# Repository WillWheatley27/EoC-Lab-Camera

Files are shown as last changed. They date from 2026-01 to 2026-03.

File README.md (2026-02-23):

| Supported Targets | ESP32 | ESP32-P4 | ESP32-S3 |
| --- | ----- | --- | --- |

# ESP32-S3 SD + Mic + OV2640 Recorder

__WARNING:__ This project writes audio/video files to the SD card. Back up your data before testing.

Records:
- **Audio**: WAV via I2S mic (ICS-43434), `mic_0001.wav`, `mic_0002.wav`, ...
- **Video**: MJPEG via OV2640, `VID0001.MJP`, `VID0002.MJP`, ...

Core features:
- SDMMC FAT mount/unmount
- USB MSC to expose the SD card when idle
- SSD1306 I2C OLED status
- Button + buzzer UI
- BLE scan trigger (advertisements) with timestamped filenames

Supports SD (SDSC, SDHC, SDXC) cards and eMMC.

## Quick wiring map (ESP32-S3)

- **SD card:** GPIO4/5/6/7/15/16 (SDMMC)
- **Mic (I2S):** GPIO19/20/21
- **OLED (I2C):** GPIO41/42 (addr `0x3C`)
- **Camera (OV2640 SCCB):**
  - SCCB SDA: GPIO47
  - SCCB SCL: GPIO48
  - XCLK: GPIO3 (10 MHz)
  - D0..D7: GPIO8, 9, 10, 11, 12, 13, 14, 17
  - PCLK: GPIO18
  - VSYNC: GPIO21
  - HREF: GPIO46
  - PWDN/RESET: tied in hardware (PWDN → GND, RESET → 3.3V)

## Hardware

This project targets ESP32-S3 and uses an SD card breakout or slot, an I2S mic, an SSD1306 OLED, and an OV2640 camera.

Although it is possible to connect an SD card breakout adapter, keep in mind that connections using breakout cables are often unreliable and have poor signal integrity. You may need to use lower clock frequency when working with SD card breakout adapters.

This project doesn't utilize card detect (CD) and write protect (WP) signals from SD card slot.

### Pin assignments for ESP32

On ESP32, SDMMC peripheral is connected to specific GPIO pins using the IO MUX. GPIO pins cannot be customized. Please see the table below for the pin connections.

When using an ESP-WROVER-KIT board, this example runs without any extra modifications required. Only an SD card needs to be inserted into the slot.

ESP32 pin     | SD card pin | Notes
--------------|-------------|------------
GPIO14 (MTMS) | CLK         | 10k pullup in SD mode
GPIO15 (MTDO) | CMD         | 10k pullup in SD mode
GPIO2         | D0          | 10k pullup in SD mode, pull low to go into download mode (see Note about GPIO2 below!)
GPIO4         | D1          | not used in 1-line SD mode; 10k pullup in 4-line SD mode
GPIO12 (MTDI) | D2          | not used in 1-line SD mode; 10k pullup in 4-line SD mode (see Note about GPIO12 below!)
GPIO13 (MTCK) | D3          | not used in 1-line SD mode, but card's D3 pin must have a 10k pullup

### Pin assignments for ESP32-S3 (current project)

On ESP32-S3, SDMMC peripheral is connected to GPIO pins using GPIO matrix. This allows arbitrary GPIOs to be used to connect an SD card. In this example, GPIOs can be configured in two ways:

1. Using menuconfig: Run `idf.py menuconfig` in the project directory and open "SD/MMC Example Configuration" menu.
2. In the source code: See the initialization of `sdmmc_slot_config_t slot_config` structure in the example code.

The table below lists the default pin assignments.

When using an ESP32-S3-USB-OTG board, this example runs without any extra modifications required. Only an SD card needs to be inserted into the slot.

ESP32-S3 pin  | SD card pin | Notes
--------------|-------------|------------
GPIO4         | CLK         | 10k pullup
GPIO5         | CMD         | 10k pullup
GPIO6         | D0          | 10k pullup
GPIO7         | D1          | 10k pullup
GPIO15        | D2          | 10k pullup
GPIO16        | D3          | 10k pullup (required even in 1-line mode)

### I2S mic (ICS-43434)

ESP32-S3 pin  | Mic pin
--------------|---------
GPIO19        | BCLK/SCK
GPIO20        | WS/LRCL
GPIO21        | DOUT/SD
3.3V          | VCC
GND           | GND

SEL/LR on the mic should be tied to GND (left channel), which matches the code.

### OLED (SSD1306, I2C)

ESP32-S3 pin  | OLED pin
--------------|---------
GPIO41        | SDA
GPIO42        | SCL
3.3V          | VCC
GND           | GND

I2C address is `0x3C`.
Note: On ESP32-S3-DevKitC-1, GPIO41/42 are JTAG pins. Disable JTAG in `idf.py menuconfig` so they can be used for I2C.

### Camera (OV2640, Waveshare) — read this first

This project uses OV2640 over SCCB (I2C). The camera is sensitive to pin choice and initial frames are often corrupted.

**Working pin map (ESP32-S3):**

ESP32-S3 pin | OV2640 pin | Notes
-------------|------------|------
GPIO47       | SCCB SDA   | Camera I2C data
GPIO48       | SCCB SCL   | Camera I2C clock
GPIO3        | XCLK       | External clock (10 MHz)
GPIO8        | D0         | Data bit 0
GPIO9        | D1         | Data bit 1
GPIO10       | D2         | Data bit 2
GPIO11       | D3         | Data bit 3
GPIO12       | D4         | Data bit 4
GPIO13       | D5         | Data bit 5
GPIO14       | D6         | Data bit 6
GPIO17       | D7         | Data bit 7
GPIO18       | PCLK       | Pixel clock
GPIO21       | VSYNC      | Frame sync
GPIO46       | HREF       | Line sync

PWDN and RESET are tied in hardware (PWDN -> GND, RESET -> 3.3V). In software, they are disabled (set to `-1`).

**What was broken and how it was fixed:**

- SCCB was originally on GPIO36/37, which are used internally by Octal flash/PSRAM on ESP32-S3-WROOM-2, so SCCB traffic failed.
  Fix: move SCCB to GPIO47/48 and set `sccb_i2c_port = I2C_NUM_0`.
- OLED and camera shared an I2C bus, and we mixed old I2C driver with a driver_ng wrapper, causing a runtime abort.
  Fix: split buses (OLED on I2C1 GPIO41/42, camera SCCB on I2C0 GPIO47/48) and remove SCCB mutex usage.
- Early frames were corrupted (NO-SOI/NO-EOI) and were written to file.
  Fix: discard the first 10 frames after init and only write frames with valid SOI/EOI markers.
- FATFS without LFN rejected long filenames.
  Fix: use 8.3 filename `VID0001.MJP`.
- OLED writes could overlap between tasks and hang I2C.
  Fix: serialize OLED I2C writes with a mutex and remove SD warning OLED spam.

**Playback note:** `VIDxxxx.MJP` is a raw MJPEG stream (not a container). VLC can play it; for QuickTime, convert to AVI/MP4.

### BLE trigger and timestamped filenames

The device scans BLE advertisements and uses a UUID-encoded timestamp to name files:

- **Video:** `MMDDHHMM.MJP`
- **Audio:** `MMDDHHMM.WAV`

If no valid BLE timestamp is seen, it falls back to the index names:

- `VID0001.MJP`
- `mic_0001.wav`

**UUID format (128-bit):** `00000000-0000-0000-TT00-YYMMDDHHMMSS`

- Prefix is fixed: all zeroes (`00 00 00 00 00 00 00 00`)
- `TT` = `01` short press, `02` long press
- `YYMMDDHHMMSS` are BCD digits (base-10 nibbles)
- Filenames use `MMDDHHMM` to stay 8.3-safe

### Button + buzzer

ESP32-S3 pin  | Device
--------------|---------
GPIO1         | Button (pull-up input)
GPIO2         | Passive buzzer (PWM output)

### Pin assignments for ESP32-P4

On ESP32-P4, Slot 1 of the SDMMC peripheral is connected to GPIO pins using GPIO matrix. This allows arbitrary GPIOs to be used to connect an SD card. In this example, GPIOs can be configured in two ways:

1. Using menuconfig: Run `idf.py menuconfig` in the project directory and open `SD/MMC Example Configuration` menu.
2. In the source code: See the initialization of `sdmmc_slot_config_t slot_config` structure in the example code.

The table below lists the default pin assignments.

ESP32-P4 pin  | SD card pin | Notes
--------------|-------------|------------
GPIO43        | CLK         | 10k pullup
GPIO44        | CMD         | 10k pullup
GPIO39        | D0          | 10k pullup
GPIO40        | D1          | not used in 1-line SD mode; 10k pullup in 4-line mode
GPIO41        | D2          | not used in 1-line SD mode; 10k pullup in 4-line mode
GPIO42        | D3          | not used in 1-line SD mode, but card's D3 pin must have a 10k pullup

Default dedicated pins on ESP32-P4 are able to connect to an ultra high-speed SD card (UHS-I) which requires 1.8V switching (instead of the regular 3.3V). This means the user has to provide an external LDO power supply to use them, or to enable and configure an internal LDO via `idf.py menuconfig` -> `SD/MMC Example Configuration` -> `SD power supply comes from internal LDO IO`.

When using different GPIO pins this is not required and `SD power supply comes from internal LDO IO` setting can be disabled.

### 4-line and 1-line SD modes

By default, this example uses 4 line SD mode, utilizing 6 pins: CLK, CMD, D0 - D3. It is possible to use 1-line mode (CLK, CMD, D0) by changing "SD/MMC bus width" in the example configuration menu (see `CONFIG_EXAMPLE_SDMMC_BUS_WIDTH_1`).

Note that even if card's D3 line is not connected to the ESP chip, it still has to be pulled up, otherwise the card will go into SPI protocol mode.

### Note about GPIO2 (ESP32 only)

GPIO2 pin is used as a bootstrapping pin, and should be low to enter UART download mode. One way to do this is to connect GPIO0 and GPIO2 using a jumper, and then the auto-reset circuit on most development boards will pull GPIO2 low along with GPIO0, when entering download mode.

- Some boards have pulldown and/or LED on GPIO2. LED is usually ok, but pulldown will interfere with D0 signals and must be removed. Check the schematic of your development board for anything connected to GPIO2.

### Note about GPIO12 (ESP32 only)

GPIO12 is used as a bootstrapping pin to select output voltage of an internal regulator which powers the flash chip (VDD_SDIO). This pin has an internal pulldown so if left unconnected it will read low at reset (selecting default 3.3V operation). When adding a pullup to this pin for SD card operation, consider the following:

- For boards which don't use the internal regulator (VDD_SDIO) to power the flash, GPIO12 can be pulled high.
- For boards which use 1.8V flash chip, GPIO12 needs to be pulled high at reset. This is fully compatible with SD card operation.
- On boards which use the internal regulator and a 3.3V flash chip, GPIO12 must be low at reset. This is incompatible with SD card operation.
    * In most cases, external pullup can be omitted and an internal pullup can be enabled using a `gpio_pullup_en(GPIO_NUM_12);` call. Most SD cards work fine when an internal pullup on GPIO12 line is enabled. Note that if ESP32 experiences a power-on reset while the SD card is sending data, high level on GPIO12 can be latched into the bootstrapping register, and ESP32 will enter a boot loop until external reset with correct GPIO12 level is applied.
    * Another option is to burn the flash voltage selection efuses. This will permanently select 3.3V output voltage for the internal regulator, and GPIO12 will not be used as a bootstrapping pin. Then it is safe to connect a pullup resistor to GPIO12. This option is suggested for production use.

The following command can be used to program flash voltage selection efuses **to 3.3V**:

```sh
    espefuse.py set_flash_voltage 3.3V
```

This command will burn the `XPD_SDIO_TIEH`, `XPD_SDIO_FORCE`, and `XPD_SDIO_REG` efuses. With all three burned to value 1, the internal VDD_SDIO flash voltage regulator is permanently enabled at 3.3V. See the technical reference manual for more details.

`espefuse.py` has a `--do-not-confirm` option if running from an automated flashing script.

See [the document about pullup requirements](https://docs.espressif.com/projects/esp-idf/en/latest/api-reference/peripherals/sd_pullup_requirements.html) for more details about pullup support and compatibility of modules and development boards.

## How to use

### Build and flash

Build the project and flash it to the board, then run monitor tool to view serial output:

```
idf.py -p PORT flash monitor
```

(Replace PORT with serial port name.)

(To exit the serial monitor, type ``Ctrl-]``.)

### Recording flow

1. Long press starts recording. USB MSC is stopped and the SD card is mounted to the app.
2. Audio is written to `mic_0001.wav`, `mic_0002.wav`, etc.
3. Long press again stops recording, finalizes the WAV header, and returns the SD card to USB MSC.
4. A later long press repeats the cycle with a new filename.

Short press toggles pause/resume during recording. Each press produces a short beep.

### SD card mount warnings

If SD mounting fails or is not ready, the OLED shows a warning:

- `SD init failed`
- `SD mount failed`
- `SD not ready`

When these appear, re-seat the SD card and try again. Also wait for the
`Exposing SD card over USB` log before unplugging or copying files.

See the Getting Started Guide for full steps to configure and use ESP-IDF to build projects.

### USB mass storage

When idle, the SD card is exposed over USB MSC for file access from your computer.
During recording, USB MSC is stopped and the SD card is mounted to the application.
After recording finishes, USB MSC is restarted and the card is visible again on the host.

## Example output

Here is an example console output. In this case a 128MB SDSC card was connected, and `EXAMPLE_FORMAT_IF_MOUNT_FAILED` menuconfig option enabled. Card was unformatted, so the initial mount has failed. Card was then partitioned, formatted, and mounted again.

```
I (336) example: Initializing SD card
I (336) example: Using SDMMC peripheral
I (420) example: Mounting filesystem
I (538) mic: Waiting for long press
I (1840) button: Recording started
I (1841) mic: Recording started
I (9620) mic: Stop requested
I (9622) mic: Captured 7 sec to /sdcard/mic_0001.wav
I (9660) example: Card unmounted
```

## Troubleshooting

### Failure to download the example

```
Connecting........_____....._____....._____....._____....._____....._____....._____

A fatal error occurred: Failed to connect to Espressif device: Invalid head of packet (0x34)
```

Disconnect the SD card D0/MISO line from GPIO2 and try uploading again. Read "Note about GPIO2" above.

### Card fails to initialize with `sdmmc_init_sd_scr: send_scr (1) returned 0x107` error

Check connections between the card and the ESP32. For example, if you have disconnected GPIO2 to work around the flashing issue, connect it back and reset the ESP32 (using a button on the development board, or by pressing Ctrl-T Ctrl-R in IDF Monitor).

### Card fails to initialize with `sdmmc_check_scr: send_scr returned 0xffffffff` error

Connections between the card and the ESP32 are too long for the frequency used. Try using shorter connections, or try reducing the clock speed of SD interface.

### Failure to mount filesystem

```
example: Failed to mount filesystem. If you want the card to be formatted, set the EXAMPLE_FORMAT_IF_MOUNT_FAILED menuconfig option.
```
The example will be able to mount only cards formatted using FAT32 filesystem. If the card is formatted as exFAT or some other filesystem, you have an option to format it in the example code. Enable the `EXAMPLE_FORMAT_IF_MOUNT_FAILED` menuconfig option, then build and flash the example.

### Debug SD connections and pullup strength

> If the initialization of the SD card fails, initially follow the above options. If the issue persists, confirm the connection of pullups to the SD pins. To do this, enable the` Debug sd pin connections and pullup strength` option from menuconfig and rerun the code. This will provide the following result:

```
**** PIN recovery time ****

PIN 14 CLK  10044 cycles
PIN 15 CMD  10034 cycles
PIN  2  D0  10034 cycles
PIN  4  D1  10034 cycles
PIN 12  D2  10034 cycles
PIN 13  D3  10034 cycles

**** PIN recovery time with weak pullup ****

PIN 14 CLK  100 cycles
PIN 15 CMD  100 cycles
PIN  2  D0  100 cycles
PIN  4  D1  100 cycles
PIN 12  D2  100 cycles
PIN 13  D3  100 cycles

**** PIN voltage levels ****

PIN 14 CLK  0.6V
PIN 15 CMD  0.3V
PIN  2  D0  0.8V
PIN  4  D1  0.6V
PIN 12  D2  0.4V
PIN 13  D3  0.8V

**** PIN voltage levels with weak pullup ****

PIN 14 CLK  1.0V
PIN 15 CMD  1.1V
PIN  2  D0  1.0V
PIN  4  D1  1.0V
PIN 12  D2  1.0V
PIN 13  D3  1.2V

**** PIN cross-talk ****

              CLK   CMD    D0    D1    D2    D3
PIN 14 CLK     --   0.2V  0.1V  0.1V  0.1V  0.2V
PIN 15 CMD    0.1V   --   0.1V  0.1V  0.1V  0.1V
PIN  2  D0    0.1V  0.1V   --   0.2V  0.1V  0.1V
PIN  4  D1    0.1V  0.1V  0.3V   --   0.1V  0.1V
PIN 12  D2    0.1V  0.2V  0.2V  0.1V   --   0.1V
PIN 13  D3    0.1V  0.2V  0.1V  0.1V  0.1V   --

**** PIN cross-talk with weak pullup ****

              CLK   CMD    D0    D1    D2    D3
PIN 14 CLK     --   1.0V  1.0V  1.0V  1.0V  1.2V
PIN 15 CMD    0.9V   --   1.0V  1.0V  1.0V  1.2V
PIN  2  D0    0.9V  1.0V   --   1.0V  1.0V  1.2V
PIN  4  D1    0.9V  1.0V  1.2V   --   1.0V  1.2V
PIN 12  D2    0.9V  1.1V  1.2V  0.9V   --   1.2V
PIN 13  D3    0.9V  1.2V  1.1V  0.9V  0.9V   --
I (845) main_task: Returned from app_main()
```

In the absence of connected pullups and having the weak pullups enabled, you can assess the pullup connections by comparing PIN recovery time measured in CPU cycles. To check pullup connections, configure the pin as open drain, set it to low state, and count the cpu cycles consumed before returning to high state. If a pullup is connected, the pin will get back to high state after reasonably small cycle count, typically around 50-300 cycles, depending on pullup strength. If no pullup is connected, the PIN stays low and the measurement times out after 10000 cycles.

It will also provide the voltage levels at the corresponding SD pins. By default, this information is provided for ESP32 chip only, and for other chipsets, verify the availability of ADC pins for the respective GPIO using [this](https://docs.espressif.com/projects/esp-idf/en/latest/esp32/api-reference/peripherals/gpio.html#gpio-summary) and configure ADC mapped pins using menuconfig. Then test the voltage levels accordingly.

You can monitor the voltage levels of individual pins using `PIN voltage levels` and `PIN voltage levels with weak pullup`. However, if one pin being pulled low and experiencing interference with another pin, you can detect it through `PIN cross-talk` and `PIN cross-talk with weak pullup`. In the absence of pullups, voltage levels at each pin should range from 0 to 0.3V. With 10k pullups connected, the voltage will be between 3.1V to 3.3V, contingent on the connection between ADC pins and SD pins, and with weak pullups connected, it can fluctuate between 0.8V to 1.2V, depending on pullup strength.
>>>>>>> 207d2c1 (Initial commit)

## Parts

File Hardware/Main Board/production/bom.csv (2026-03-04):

Designator | Footprint | Quantity | Value | LCSC Part #
BOOT1, RESET1 | SW_SPST_EVQP7A | 2 | SW_Push
BT1 | JST_GH_SM02B-GHS-TB_1x02-1MP_P1.25mm_Horizontal | 1 | Battery_Cell
C1, C3, C8 | 0402 | 3 | 0.1uF
C10, C2, C7 | 0402 | 3 | 10uF
C11, C12, C13 | 0805 | 3 | 22uF
C4, C5, C6 | 0603 | 3 | 10uF
C9 | 0402 | 1 | 10pF
D1, D2, D3, D4 | 0603 | 4 | LED
D5 | D_SMA | 1 | SS14
F1 | 1206 | 1 | Fuse
J1 | microSD_HC_Molex_104031-0811 | 1 | Micro_SD_Card_Det1
J2 | PinHeader_2x09_P2.54mm_Vertical | 1 | Camera Module
J3 | JST_GH_SM09B-GHS-TB_1x09-1MP_P1.25mm_Horizontal | 1 | Conn_01x09_Socket
J4 | JST_GH_SM06B-GHS-TB_1x06-1MP_P1.25mm_Horizontal | 1 | MIC 1 Connector
J5 | JST_GH_SM06B-GHS-TB_1x06-1MP_P1.25mm_Horizontal | 1 | MIC 2 Connector
J6 | USB_C_Receptacle_HRO_TYPE-C-31-M-12 | 1 | USB_C_Receptacle_USB2.0_16P
J7 | PinHeader_1x04_P2.54mm_Vertical | 1 | OLED
L1 | L_Bourns-SRN4018 | 1 | 1uH
Q1 | SOT-23 | 1 | AO3401A
R1, R11, R12 | 0402 | 3 | 10k
R10, R23, R8, R9 | 0402 | 4 | 22
R13, R14, R20 | 0402 | 3 | 1k
R15 | 0402 | 1 | 0.4
R16 | 0402 | 1 | 560k
R17 | 0402 | 1 | 4.7k
R18, R24 | 0402 | 2 | 100k
R19 | 0402 | 1 | 1M
R2, R3, R4, R5, R6, R7 | 0402 | 6 | 47k
R21, R22 | 0402 | 2 | 5.1k
TP1, TP2, TP3 | PinHeader_1x01_P2.54mm_Vertical | 3 | TestPoint
TP4, TP5, TP6 | TestPoint_Pad_1.0x1.0mm | 3 | TestPoint
U1 | ESP32-S3-WROOM-2 | 1 | ESP32-S3-WROOM-2
U2 | Texas_S-PWSON-N10_ThermalVias | 1 | TPS63060
U3 | SOIC-8-1EP_3.9x4.9mm_P1.27mm_EP2.41x3.3mm_ThermalVias | 1 | TP4056-42-ESOP8
USER_INPUT1 | SW_SPST_PTS645 | 1 | SW_Push

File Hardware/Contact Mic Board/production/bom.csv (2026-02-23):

Designator | Footprint | Quantity | Value | LCSC Part #
C1, C16, C18, C19, C3, C5, C6 | 0402 | 7 | 0.1uF
C10, C13, C8, C9 | 0402 | 4 | 1uF
C11, C12 | 0402 | 2 | 470nF
C14, C15, C17, C2, C4, C7 | 0402 | 6 | 10uF
FB1 | 0603 | 1 | FerriteBead_Small
J1 | JST_GH_SM09B-GHS-TB_1x09-1MP_P1.25mm_Horizontal | 1 | Conn_01x09_Pin
R1, R2 | 0402 | 2 | 47k
R10, R9 | 0402 | 2 | 1M
R11, R12, R13, R14 | 0402 | 4 | 33
R3, R4 | 0402 | 2 | 10M
R5, R6 | 0805 | 2 | 100k
R7, R8 | 0402 | 2 | 10K
U1 | QFN-28-1EP_4x4mm_P0.45mm_EP2.6x2.6mm | 1 | ES8388
U2 | DFN-8-1EP_3x2mm_P0.5mm_EP1.75x1.45mm | 1 | MCP6002-xMC

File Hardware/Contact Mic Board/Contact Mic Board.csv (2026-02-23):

Reference | Qty | Value | DNP | Exclude from BOM | Exclude from Board | Footprint | Datasheet
C1,C3,C5,C6,C16,C18,C19 | 7 | 0.1uF |  |  |  | Capacitor_SMD:C_0402_1005Metric | ~
C2,C4,C7,C14,C15,C17 | 6 | 10uF |  |  |  | Capacitor_SMD:C_0402_1005Metric | ~
C8,C9,C10,C13 | 4 | 1uF |  |  |  | Capacitor_SMD:C_0402_1005Metric | ~
C11,C12 | 2 | 470nF |  |  |  | Capacitor_SMD:C_0402_1005Metric | ~
FB1 | 1 | FerriteBead_Small |  |  |  | Capacitor_SMD:C_0603_1608Metric | ~
J1 | 1 | Conn_01x09_Pin |  |  |  | Connector_JST:JST_GH_SM09B-GHS-TB_1x09-1MP_P1.25mm_Horizontal | ~
MIC1 | 1 | Contact Mic 1 |  | Excluded from BOM |  | Connector_PinHeader_2.54mm:PinHeader_1x02_P2.54mm_Vertical | ~
MIC2 | 1 | Contact Mic 2 |  | Excluded from BOM |  | Connector_PinHeader_2.54mm:PinHeader_1x02_P2.54mm_Vertical | ~
R1,R2 | 2 | 47k |  |  |  | Capacitor_SMD:C_0402_1005Metric | ~
R3,R4 | 2 | 10M |  |  |  | Capacitor_SMD:C_0402_1005Metric | ~
R5,R6 | 2 | 100k |  |  |  | Diode_SMD:D_0805_2012Metric_Pad1.15x1.40mm_HandSolder | ~
R7 | 1 | 10K |  |  |  | Capacitor_SMD:C_0402_1005Metric | ~
R8 | 1 | 10k |  |  |  | Capacitor_SMD:C_0402_1005Metric | ~
R9,R10 | 2 | 1M |  |  |  | Capacitor_SMD:C_0402_1005Metric | ~
R11,R12,R13,R14 | 4 | 33 |  |  |  | Capacitor_SMD:C_0402_1005Metric | ~
TP1,TP2,TP3,TP4 | 4 | TestPoint |  |  |  | TestPoint:TestPoint_Pad_1.0x1.0mm | ~
U1 | 1 | ES8388 |  |  |  | Package_DFN_QFN:QFN-28-1EP_4x4mm_P0.45mm_EP2.6x2.6mm | http://www.everest-semi.com/pdf/ES8388%20DS.pdf
U2 | 1 | MCP6002-xMC |  |  |  | Package_DFN_QFN:DFN-8-1EP_3x2mm_P0.5mm_EP1.75x1.45mm | http://ww1.microchip.com/downloads/en/DeviceDoc/21733j.pdf

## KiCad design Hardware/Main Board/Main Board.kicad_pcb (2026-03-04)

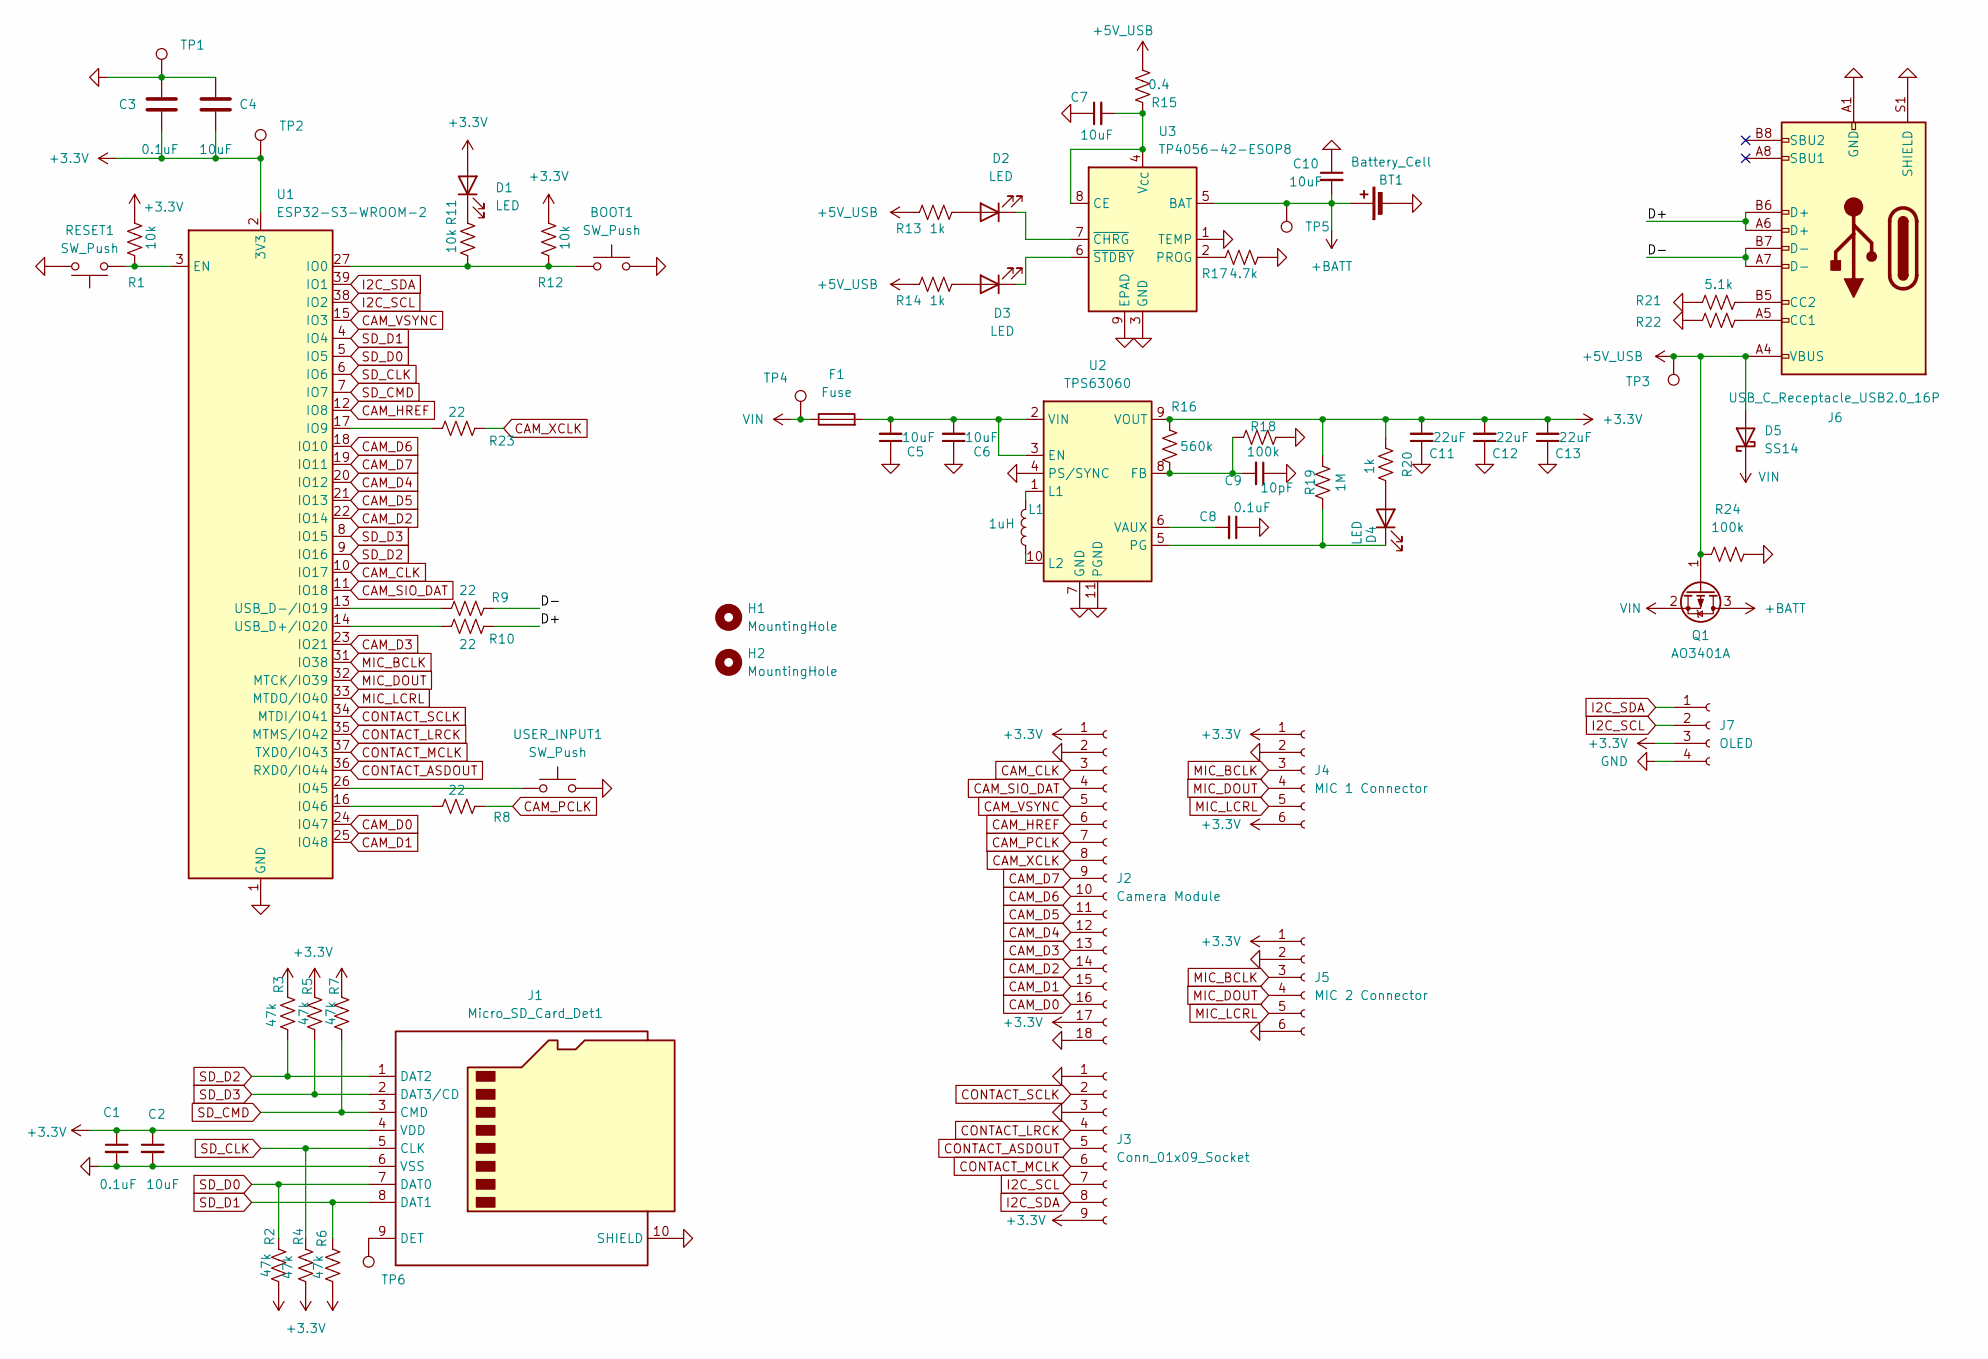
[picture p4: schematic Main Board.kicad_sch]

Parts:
BOOT1: SW_Push; SW_SPST_EVQP7A
BT1: Battery_Cell; JST_GH_SM02B-GHS-TB_1x02-1MP_P1.25mm_Horizontal
C1, C3, C8: 0.1uF; C_0402_1005Metric
C2, C7, C10: 10uF; C_0402_1005Metric
C4, C5, C6: 10uF; C_0603_1608Metric
C9: 10pF; C_0402_1005Metric
C11, C12, C13: 22uF; C_0805_2012Metric
D1, D2, D3, D4: LED; LED_0603_1608Metric
D5: SS14; D_SMA
F1: Fuse; Fuse_1206_3216Metric
H1, H2: MountingHole; MountingHole_2.1mm
J1: Micro_SD_Card_Det1; microSD_HC_Molex_104031-0811
J2: Camera Module; PinHeader_2x09_P2.54mm_Vertical
J3: Conn_01x09_Socket; JST_GH_SM09B-GHS-TB_1x09-1MP_P1.25mm_Horizontal
J4: MIC 1 Connector; JST_GH_SM06B-GHS-TB_1x06-1MP_P1.25mm_Horizontal
J5: MIC 2 Connector; JST_GH_SM06B-GHS-TB_1x06-1MP_P1.25mm_Horizontal
J6: USB_C_Receptacle_USB2.0_16P; USB_C_Receptacle_HRO_TYPE-C-31-M-12
J7: OLED; PinHeader_1x04_P2.54mm_Vertical
L1: 1uH; L_Bourns-SRN4018
Q1: AO3401A; SOT-23
R1, R11, R12: 10k; R_0402_1005Metric
R2, R3, R4, R5, R6, R7: 47k; R_0402_1005Metric
R8, R9, R10, R23: 22; R_0402_1005Metric
R13, R14, R20: 1k; R_0402_1005Metric
R15: 0.4; R_0402_1005Metric
R16: 560k; R_0402_1005Metric
R17: 4.7k; R_0402_1005Metric
R18, R24: 100k; R_0402_1005Metric
R19: 1M; R_0402_1005Metric
R21, R22: 5.1k; R_0402_1005Metric
RESET1: SW_Push; SW_SPST_EVQP7A
TP1, TP2, TP3: TestPoint; PinHeader_1x01_P2.54mm_Vertical
TP4, TP5, TP6: TestPoint; TestPoint_Pad_1.0x1.0mm
U1: ESP32-S3-WROOM-2
U2: TPS63060; Texas_S-PWSON-N10_ThermalVias
U3: TP4056-42-ESOP8; SOIC-8-1EP_3.9x4.9mm_P1.27mm_EP2.41x3.3mm_ThermalVias
USER_INPUT1: SW_Push; SW_SPST_PTS645

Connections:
+3.3V: C1.1, C2.1, C3.2, C4.1, C11.2, C12.2, C13.2, D1.2 (A), J1.4 (VDD), J2.1, J2.17, J3.9, J4.1, J4.6, J5.1, J7.3, R1.1, R2.1, R3.2, R4.1, R5.2, R6.1, R7.2, R12.1, R16.2, R19.2, R20.2, TP2.1, U1.2 (3V3), U2.9 (VOUT)
+5V_USB: D5.2 (A), J6.A4 (VBUS), J6.A9 (VBUS), J6.B4 (VBUS), J6.B9 (VBUS), Q1.1 (G), R13.2, R14.2, R15.1, R24.1, TP3.1
+BATT: BT1.1 (+), C10.2, Q1.3 (D), TP5.1, U3.5 (BAT)
/D+: J6.A6 (D+), J6.B6 (D+), R10.1
/D-: J6.A7 (D-), J6.B7 (D-), R9.1
CAM_CLK: J2.3, U1.10 (IO17)
CAM_D0: J2.16, U1.24 (IO47)
CAM_D1: J2.15, U1.25 (IO48)
CAM_D2: J2.14, U1.22 (IO14)
CAM_D3: J2.13, U1.23 (IO21)
CAM_D4: J2.12, U1.20 (IO12)
CAM_D5: J2.11, U1.21 (IO13)
CAM_D6: J2.10, U1.18 (IO10)
CAM_D7: J2.9, U1.19 (IO11)
CAM_HREF: J2.6, U1.12 (IO8)
CAM_PCLK: J2.7, R8.2
CAM_SIO_DAT: J2.4, U1.11 (IO18)
CAM_VSYNC: J2.5, U1.15 (IO3)
CAM_XCLK: J2.8, R23.2
CONTACT_ASDOUT: J3.5, U1.36 (RXD0/IO44)
CONTACT_LRCK: J3.4, U1.35 (MTMS/IO42)
CONTACT_MCLK: J3.6, U1.37 (TXD0/IO43)
CONTACT_SCLK: J3.2, U1.34 (MTDI/IO41)
GND: BOOT1.2, BT1.2 (-), C1.2, C2.2, C3.1, C4.2, C5.1, C6.1, C7.1, C8.1, C9.1, C10.1, C11.1, C12.1, C13.1, J1.6 (VSS), J1.10 (SHIELD), J2.2, J2.18, J3.1, J3.3, J4.2, J5.2, J5.6, J6.A1 (GND), J6.A12 (GND), J6.B1 (GND), J6.B12 (GND), J6.S1 (SHIELD), J7.4, R17.1, R18.1, R21.2, R22.2, R24.2, RESET1.2, TP1.1, U1.1 (GND), U1.40 (GND), U1.41 (GND), U2.4 (PS/SYNC), U2.7 (GND), U2.11 (PGND), U3.1 (TEMP), U3.3 (GND), U3.9 (EPAD), USER_INPUT1.2
I2C_SCL: J3.7, J7.2, U1.38 (IO2)
I2C_SDA: J3.8, J7.1, U1.39 (IO1)
MIC_BCLK: J4.3, J5.3, U1.31 (IO38)
MIC_DOUT: J4.4, J5.4, U1.32 (MTCK/IO39)
MIC_LCRL: J4.5, J5.5, U1.33 (MTDO/IO40)
unnamed: D1.1 (K), R11.2
unnamed: D2.2 (A), R13.1
unnamed: D2.1 (K), U3.7 (~CHRG)
unnamed: D3.2 (A), R14.1
unnamed: D3.1 (K), U3.6 (~STDBY)
unnamed: D4.2 (A), R20.1
unnamed: D4.1 (K), R19.1, U2.5 (PG)
unnamed: J1.9 (DET), TP6.1
unnamed: J6.A5 (CC1), R22.1
unnamed: J6.B5 (CC2), R21.1
unnamed: R1.2, RESET1.1, U1.3 (EN)
unnamed: BOOT1.1, R11.1, R12.2, U1.27 (IO0)
unnamed: R23.1, U1.17 (IO9)
unnamed: U1.26 (IO45), USER_INPUT1.1
unnamed: R8.1, U1.16 (IO46)
unnamed: R10.2, U1.14 (USB_D+/IO20)
unnamed: R9.2, U1.13 (USB_D-/IO19)
unnamed: C5.2, C6.2, F1.2, U2.2 (VIN), U2.3 (EN)
unnamed: C9.2, R16.1, R18.2, U2.8 (FB)
unnamed: L1.2, U2.1 (L1)
unnamed: L1.1, U2.10 (L2)
unnamed: C8.2, U2.6 (VAUX)
unnamed: C7.2, R15.2, U3.4 (V_{CC}), U3.8 (CE)
unnamed: R17.2, U3.2 (PROG)
SD_CLK: J1.5 (CLK), R4.2, U1.6 (IO6)
SD_CMD: J1.3 (CMD), R7.1, U1.7 (IO7)
SD_D0: J1.7 (DAT0), R2.2, U1.5 (IO5)
SD_D1: J1.8 (DAT1), R6.2, U1.4 (IO4)
SD_D2: J1.1 (DAT2), R3.1, U1.9 (IO16)
SD_D3: J1.2 (DAT3/CD), R5.1, U1.8 (IO15)
VIN: D5.1 (K), F1.1, Q1.2 (S), TP4.1

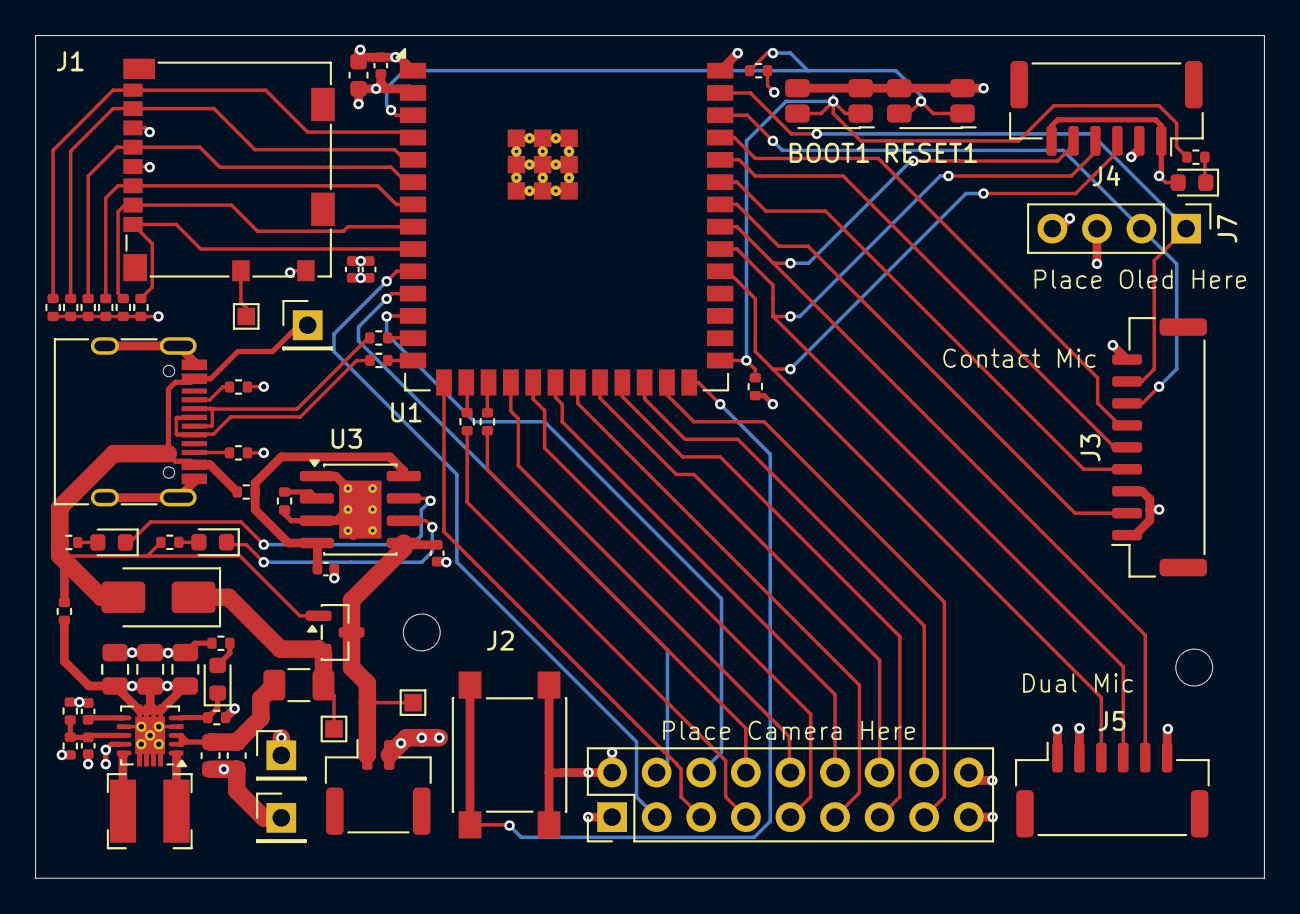
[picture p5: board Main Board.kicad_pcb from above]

Board: 4 copper layers, 70.0 x 48.0 mm, 67 parts (0 on the bottom side), 60 nets.

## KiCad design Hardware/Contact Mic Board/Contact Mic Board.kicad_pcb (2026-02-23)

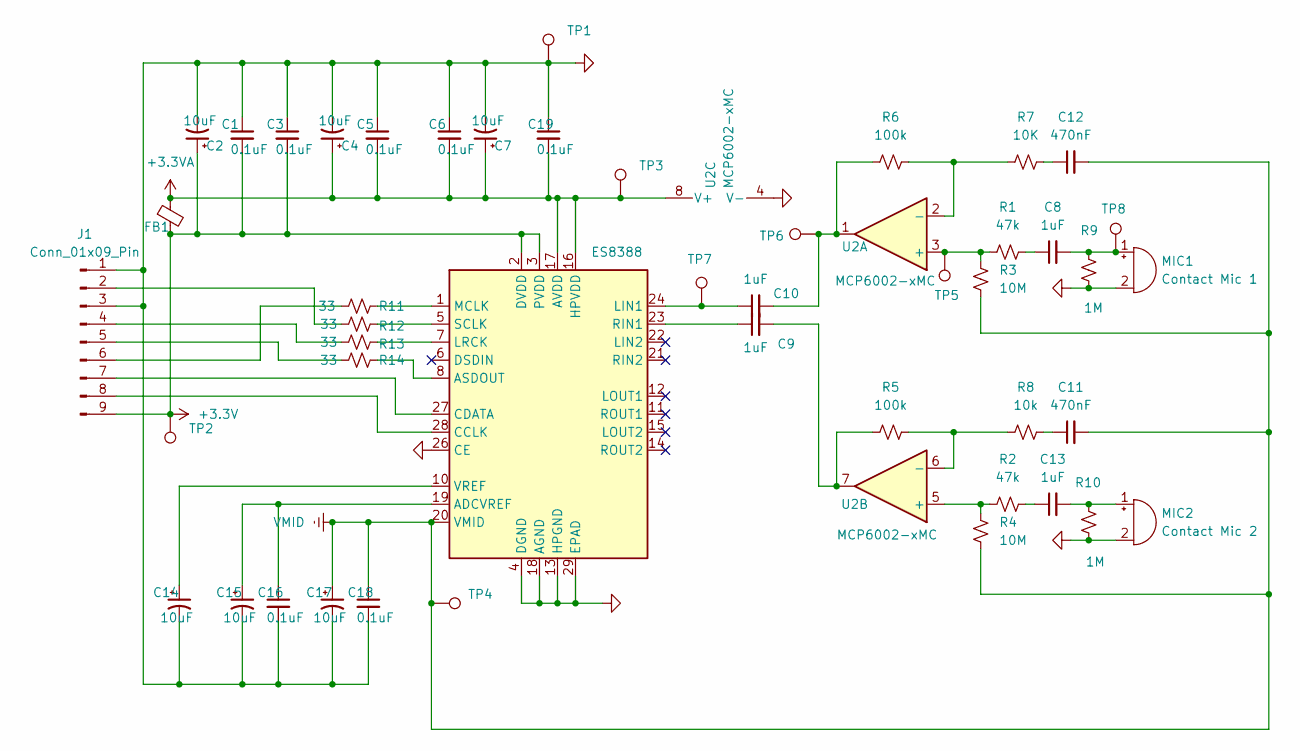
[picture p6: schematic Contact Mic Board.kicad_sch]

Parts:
C1, C3, C5, C6, C16, C18, C19: 0.1uF; C_0402_1005Metric
C2, C4, C7, C14, C15, C17: 10uF; C_0402_1005Metric
C8, C9, C10, C13: 1uF; C_0402_1005Metric
C11, C12: 470nF; C_0402_1005Metric
FB1: FerriteBead_Small; C_0603_1608Metric
J1: Conn_01x09_Pin; JST_GH_SM09B-GHS-TB_1x09-1MP_P1.25mm_Horizontal
MIC1: Contact Mic 1; PinHeader_1x02_P2.54mm_Vertical
MIC2: Contact Mic 2; PinHeader_1x02_P2.54mm_Vertical
R1, R2: 47k; C_0402_1005Metric
R3, R4: 10M; C_0402_1005Metric
R5, R6: 100k; D_0805_2012Metric_Pad1.15x1.40mm_HandSolder
R7: 10K; C_0402_1005Metric
R8: 10k; C_0402_1005Metric
R9, R10: 1M; C_0402_1005Metric
R11, R12, R13, R14: 33; C_0402_1005Metric
TP1, TP2, TP3, TP4, TP5, TP6, TP7, TP8: TestPoint; TestPoint_Pad_1.0x1.0mm
U1: ES8388; QFN-28-1EP_4x4mm_P0.45mm_EP2.6x2.6mm
U2: MCP6002-xMC; DFN-8-1EP_3x2mm_P0.5mm_EP1.75x1.45mm

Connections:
+3.3V: C1.2, C2.1, C3.2, FB1.2, J1.9, TP2.1, U1.2 (DVDD), U1.3 (PVDD)
+3.3VA: C4.1, C5.2, C6.2, C7.1, C19.2, FB1.1, TP3.1, U1.16 (HPVDD), U1.17 (AVDD), U2.8 (V+)
GND: C1.1, C2.2, C3.1, C4.2, C5.1, C6.1, C7.2, C14.2, C15.2, C16.2, C17.2, C18.2, C19.1, J1.1, J1.3, MIC1.2 (-), MIC2.2 (-), R9.2, R10.2, TP1.1, U1.4 (DGND), U1.13 (HPGND), U1.18 (AGND), U1.26 (CE), U1.29 (EPAD), U2.4 (V-), U2.9 (V-)
unnamed: C8.1, R1.2
unnamed: C9.2, R5.2, U2.7
unnamed: C10.2, R6.1, TP6.1, U2.1
unnamed: C11.1, R8.2
unnamed: C12.1, R7.2
unnamed: C13.1, R2.2
unnamed: J1.2, R12.1
unnamed: J1.4, R13.1
unnamed: J1.5, R14.1
unnamed: J1.6, R11.1
unnamed: J1.7, U1.27 (CDATA)
unnamed: J1.8, U1.28 (CCLK)
unnamed: C8.2, MIC1.1 (+), R9.1, TP8.1
unnamed: C13.2, MIC2.1 (+), R10.1
unnamed: C15.1, C16.1, U1.19 (ADCVREF)
unnamed: R14.2, U1.8 (ASDOUT)
unnamed: C10.1, TP7.1, U1.24 (LIN1)
unnamed: R13.2, U1.7 (LRCK)
unnamed: R11.2, U1.1 (MCLK)
unnamed: C9.1, U1.23 (RIN1)
unnamed: R12.2, U1.5 (SCLK)
unnamed: C14.1, U1.10 (VREF)
unnamed: R1.1, R3.1, TP5.1, U2.3 (+)
unnamed: R6.2, R7.1, U2.2 (-)
unnamed: R2.1, R4.1, U2.5 (+)
unnamed: R5.1, R8.1, U2.6 (-)
VMID: C11.2, C12.2, C17.1, C18.1, R3.2, R4.2, TP4.1, U1.20 (VMID)

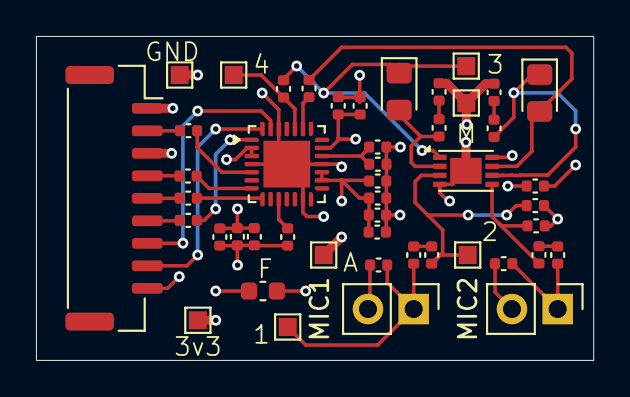
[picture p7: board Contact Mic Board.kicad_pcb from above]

Board: 4 copper layers, 31.0 x 18.0 mm, 47 parts (0 on the bottom side), 30 nets.

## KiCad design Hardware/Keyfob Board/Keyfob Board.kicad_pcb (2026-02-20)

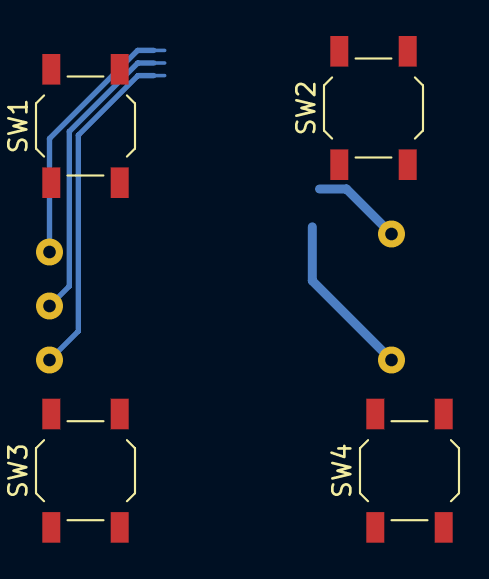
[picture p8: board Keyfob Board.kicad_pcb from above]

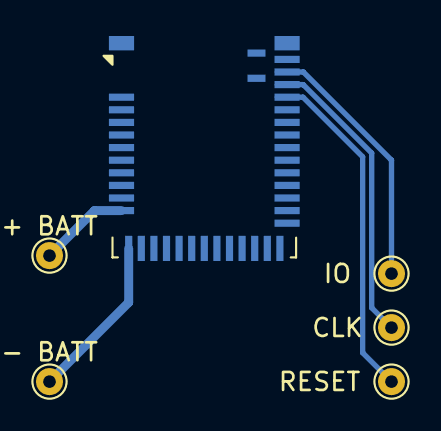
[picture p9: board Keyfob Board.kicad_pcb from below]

Board: 2 copper layers, 10 parts (6 on the bottom side), 9 nets.

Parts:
+ BATT: TestPoint; TestPoint_THTPad_D1.5mm_Drill0.7mm
- BATT: TestPoint; TestPoint_THTPad_D1.5mm_Drill0.7mm
CLK: TestPoint; TestPoint_THTPad_D1.5mm_Drill0.7mm
IO: TestPoint; TestPoint_THTPad_D1.5mm_Drill0.7mm
RESET: TestPoint; TestPoint_THTPad_D1.5mm_Drill0.7mm
SW1, SW2, SW3, SW4: SW_Push; SW_SPST_TL3342
U1: MDBT42Q-512K; Raytac_MDBT42Q

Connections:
+BATT: + BATT.1, U1.11 (VDD)
-BATT: - BATT.1, SW1.2, SW2.2, SW3.2, SW4.2, U1.1 (GND), U1.12 (GND), U1.24 (GND), U1.39 (GND)
unnamed: SW1.1, U1.25 (P0.11)
unnamed: SW2.1, U1.26 (P0.12)
unnamed: RESET.1, U1.35 (P0.21/~RESET)
unnamed: SW3.1, U1.40 (P0.24)
unnamed: SW4.1, U1.2 (P0.25)
unnamed: CLK.1, U1.36 (SWDCLK)
unnamed: IO.1, U1.37 (SWDIO)

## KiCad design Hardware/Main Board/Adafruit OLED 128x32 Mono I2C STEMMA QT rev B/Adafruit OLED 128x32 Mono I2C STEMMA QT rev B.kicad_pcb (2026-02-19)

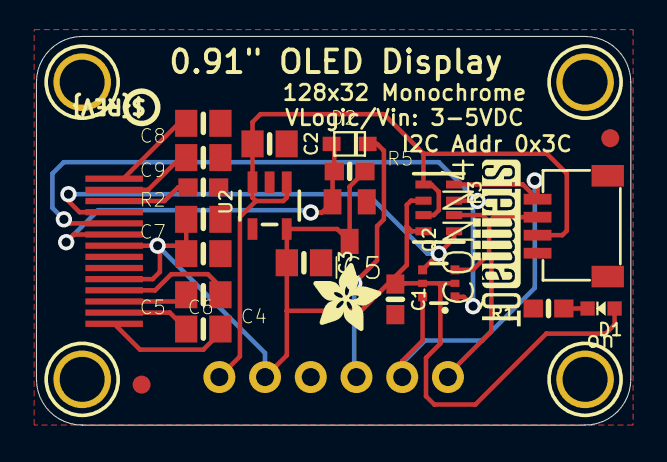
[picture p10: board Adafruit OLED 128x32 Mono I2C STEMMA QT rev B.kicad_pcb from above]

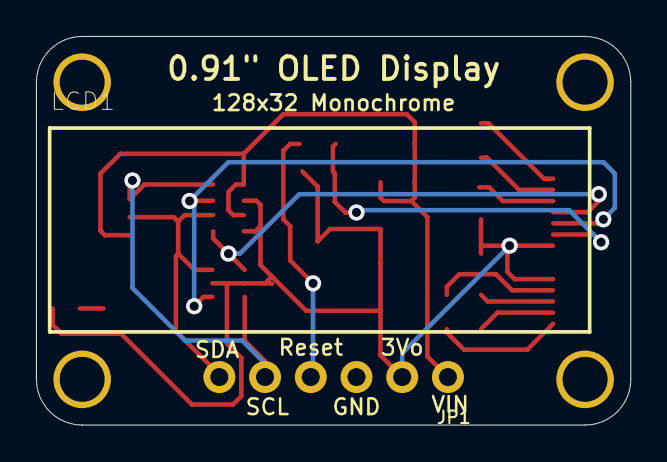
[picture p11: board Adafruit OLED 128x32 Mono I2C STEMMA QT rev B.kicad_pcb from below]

Board: 2 copper layers, 33.0 x 21.6 mm, 30 parts (2 on the bottom side), 17 nets.

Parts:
C1: 0.1uF; 0603-NO
C2, C3, C8, C9: 10uF; 0805-NO
C4, C5, C6, C7: 1uF; 0805-NO
CONN4: STEMMA_I2C_QT; JST_SH4
D1: GREEN; CHIPLED_0603_NOOUTLINE
D2: 1N4148; SOD-323F
FID3, FID4: FIDUCIAL_1MM
IC5: APX803; SOT23
JP1: 1X06_ROUND_70
LCD1: UG-2832HSWEG02_WRAPUNDER
Q2: BSS138; SOT363
R1, R5: 10K; 0603-NO
R2: 390K; 0603-NO
R3: 10K; RESPACK_4X0603
U2: AP2112K-3.3; SOT23-5
U$1, U$17, U$19, U$21: MOUNTINGHOLE2.5; MOUNTINGHOLE_2.5_PLATED
U$22: ADAFRUIT_3.5MM
U$25: PCBFEAT-REV-040
U$31: STEMMAQT

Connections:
3.3V: C1.1, C3.1, C6.2, C7.2, D1.A, IC5.3, JP1.2, LCD1.5, LCD1.8, Q2.2, Q2.5, R3.2, R3.4, R5.2, U2.5
GND: C1.2, C2.2, C3.2, C6.1, C7.1, C8.1, C9.1, CONN4.1, IC5.1, JP1.3, LCD1.7, R1.2, R2.1, U2.2
unnamed: C4.2, LCD1.1
unnamed: D1.C, R1.1
unnamed: C4.1, LCD1.2
unnamed: C5.2, LCD1.3
unnamed: C5.1, LCD1.4
unnamed: C9.2, LCD1.13
unnamed: LCD1.12, R2.2
unnamed: C8.2, LCD1.14
RESET: D2.C, JP1.4
RES_3V: D2.A, IC5.2, LCD1.9, R5.1
SCL: CONN4.4, JP1.5, Q2.6, R3.8
SCL_3V: LCD1.10, Q2.1, R3.7
SDA: CONN4.3, JP1.6, Q2.3, R3.6
SDA_3V: LCD1.11, Q2.4, R3.5
VCC: C2.1, CONN4.2, JP1.1, R3.1, R3.3, U2.1, U2.3

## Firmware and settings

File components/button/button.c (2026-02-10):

#include "button.h"

#include <stdint.h>

#include "driver/gpio.h"
#include "driver/ledc.h"
#include "freertos/FreeRTOS.h"
#include "freertos/task.h"
#include "esp_err.h"
#include "esp_log.h"
#include "oled_ssd1306.h"

#define BUTTON_GPIO GPIO_NUM_1
#define BUZZER_GPIO GPIO_NUM_2
#define DEBOUNCE_MS 30
#define LONG_PRESS_MS 500
#define BUZZER_PULSE_MS 50
#define BUZZER_FREQ_HZ 2000
#define BUZZER_DUTY_RES LEDC_TIMER_10_BIT

static const char *TAG = "button";

static volatile bool s_paused = false;
static volatile bool s_recording = false;
static volatile TickType_t s_record_start_tick = 0;
static char s_status_line[64] = "Ready";
static TickType_t s_oled_next_retry_tick = 0;
static uint8_t s_oled_fail_count = 0;

// Logs button state changes to the console.
static void s_log_info(const char *text)
{
    ESP_LOGI(TAG, "%s", text);
}

// Plays a short buzzer pulse for feedback.
static void s_buzzer_pulse(void)
{
    ledc_set_duty(LEDC_LOW_SPEED_MODE, LEDC_CHANNEL_0, (1 << BUZZER_DUTY_RES) / 2);
    ledc_update_duty(LEDC_LOW_SPEED_MODE, LEDC_CHANNEL_0);
    vTaskDelay(pdMS_TO_TICKS(BUZZER_PULSE_MS));
    ledc_set_duty(LEDC_LOW_SPEED_MODE, LEDC_CHANNEL_0, 0);
    ledc_update_duty(LEDC_LOW_SPEED_MODE, LEDC_CHANNEL_0);
}

static void s_handle_short_press(void)
{
    if (s_recording) {
        s_paused = !s_paused;
        s_log_info(s_paused ? "Paused" : "Recording");
    }
    s_buzzer_pulse();
}

static void s_handle_long_press(void)
{
    if (s_recording) {
        s_recording = false;
        s_paused = false;
        s_log_info("Recording stopped");
    } else {
        s_recording = true;
        s_paused = false;
        s_record_start_tick = xTaskGetTickCount();
        s_log_info("Recording started");
    }
    s_buzzer_pulse();
}

// Updates the OLED with timer/status once per second.
static void s_oled_task(void *arg)
{
    (void)arg;
    char buffer[64];
    while (true) {
        if (s_oled_next_retry_tick != 0 && xTaskGetTickCount() < s_oled_next_retry_tick) {
            vTaskDelay(pdMS_TO_TICKS(200));
            continue;
        }
        esp_err_t ret;
        if (s_recording) {
            TickType_t elapsed_ticks = xTaskGetTickCount() - s_record_start_tick;
            uint32_t elapsed_seconds = (uint32_t)(elapsed_ticks / configTICK_RATE_HZ);
            uint32_t hours = elapsed_seconds / 3600;
            uint32_t minutes = (elapsed_seconds % 3600) / 60;
            uint32_t seconds = elapsed_seconds % 60;
            const char *line2 = s_paused ? "Paused" : "Recording";
            snprintf(buffer, sizeof(buffer), "%02lu:%02lu:%02lu\n%s",
                     (unsigned long)hours,
                     (unsigned long)minutes,
                     (unsigned long)seconds,
                     line2);
            ret = oled_ssd1306_display_text(buffer);
        } else {
            ret = oled_ssd1306_display_text(s_status_line);
        }
        if (ret != ESP_OK) {
            s_oled_fail_count++;
            if (s_oled_fail_count == 1) {
                oled_ssd1306_init();
            }
            if (s_oled_fail_count >= 3) {
                s_oled_next_retry_tick = xTaskGetTickCount() + pdMS_TO_TICKS(5000);
                s_oled_fail_count = 0;
            }
        } else {
            s_oled_fail_count = 0;
            s_oled_next_retry_tick = 0;
        }
        vTaskDelay(pdMS_TO_TICKS(1000));
    }
}

// Handles debounced button presses and toggles recording state.
static void s_button_task(void *arg)
{
    (void)arg;
    bool last_level = true;
    TickType_t press_tick = 0;

    while (true) {
        bool level = gpio_get_level(BUTTON_GPIO);
        if (level != last_level) {
            vTaskDelay(pdMS_TO_TICKS(DEBOUNCE_MS));
            level = gpio_get_level(BUTTON_GPIO);
            if (level != last_level) {
                last_level = level;
                if (!level) {
                    press_tick = xTaskGetTickCount();
                } else {
                    TickType_t held = xTaskGetTickCount() - press_tick;
                    if (held >= pdMS_TO_TICKS(LONG_PRESS_MS)) {
                        s_handle_long_press();
                    } else {
                        s_handle_short_press();
                    }
                }
            }
        }
        vTaskDelay(pdMS_TO_TICKS(10));
    }
}

// Initializes GPIO, buzzer, and background tasks.
void button_init(void)
{
    gpio_config_t cfg = {
        .pin_bit_mask = 1ULL << BUTTON_GPIO,
        .mode = GPIO_MODE_INPUT,
        .pull_up_en = GPIO_PULLUP_ENABLE,
        .pull_down_en = GPIO_PULLDOWN_DISABLE,
        .intr_type = GPIO_INTR_DISABLE,
    };
    gpio_config(&cfg);

    ledc_timer_config_t buzzer_timer = {
        .speed_mode = LEDC_LOW_SPEED_MODE,
        .timer_num = LEDC_TIMER_0,
        .duty_resolution = BUZZER_DUTY_RES,
        .freq_hz = BUZZER_FREQ_HZ,
        .clk_cfg = LEDC_AUTO_CLK,
    };
    ledc_timer_config(&buzzer_timer);

    ledc_channel_config_t buzzer_channel = {
        .speed_mode = LEDC_LOW_SPEED_MODE,
        .channel = LEDC_CHANNEL_0,
        .timer_sel = LEDC_TIMER_0,
        .intr_type = LEDC_INTR_DISABLE,
        .gpio_num = BUZZER_GPIO,
        .duty = 0,
        .hpoint = 0,
    };
    ledc_channel_config(&buzzer_channel);

    xTaskCreate(s_button_task, "button_task", 4096, NULL, 10, NULL);
    xTaskCreate(s_oled_task, "oled_task", 4096, NULL, 5, NULL);
}

// Sets the idle OLED display lines shown when not recording.
void button_set_idle_display(const char *line1, const char *line2)
{
    if (line1 == NULL) {
        line1 = "";
    }
    if (line2 == NULL) {
        line2 = "";
    }
    snprintf(s_status_line, sizeof(s_status_line), "%s\n%s", line1, line2);
}

// Returns whether recording is currently paused.
bool button_is_paused(void)
{
    return s_paused;
}

// Returns whether recording is currently active.
bool button_is_recording(void)
{
    return s_recording;
}

void button_trigger_short_press(void)
{
    s_handle_short_press();
}

void button_trigger_long_press(void)
{
    s_handle_long_press();
}

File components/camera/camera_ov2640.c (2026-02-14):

#include "camera_ov2640.h"

#include <errno.h>
#include <stdio.h>
#include <stdlib.h>
#include <string.h>
#include <unistd.h>

#include "button.h"
#include "driver/i2c.h"
#include "driver/gpio.h"
#include "esp_camera.h"
#include "esp_heap_caps.h"
#include "esp_log.h"
#include "freertos/FreeRTOS.h"
#include "freertos/task.h"
#include "img_converters.h"

void camera_ov2640_get_default_pins(camera_ov2640_pins_t *pins)
{
    if (!pins) {
        return;
    }

    *pins = (camera_ov2640_pins_t){
        .pin_d0 = 8,
        .pin_d1 = 9,
        .pin_d2 = 10,
        .pin_d3 = 11,
        .pin_d4 = 12,
        .pin_d5 = 13,
        .pin_d6 = 14,
        .pin_d7 = 17,
        .pin_pclk = 18,
        .pin_vsync = 21,
        .pin_href = 46,
        .pin_xclk = 3,
        .pin_sda = 47,
        .pin_scl = 48,
        .pin_pwdn = -1,
        .pin_reset = -1,
    };
}

#define VIDEO_FRAME_SIZE   FRAMESIZE_VGA
#define VIDEO_JPEG_QUALITY 12
#define VIDEO_XCLK_HZ      10000000
#define VIDEO_FLUSH_BYTES  (4 * 1024 * 1024)

static const char *TAG = "example";

typedef struct {
    char path[64];
} camera_task_args_t;

static TaskHandle_t s_camera_task = NULL;
static bool s_camera_ready = false;
static uint8_t *s_black_jpeg = NULL;
static size_t s_black_jpeg_len = 0;
static bool s_psram_ok = false;

// Returns the resolution for the selected camera frame size.
static void s_frame_size_to_dim(framesize_t size, int *width, int *height)
{
    switch (size) {
        case FRAMESIZE_QQVGA:
            *width = 160;
            *height = 120;
            break;
        case FRAMESIZE_QVGA:
            *width = 320;
            *height = 240;
            break;
        case FRAMESIZE_VGA:
            *width = 640;
            *height = 480;
            break;
        default:
            *width = 640;
            *height = 480;
            break;
    }
}

// Builds a black JPEG frame that can be reused while paused.
static esp_err_t s_prepare_black_frame(framesize_t size, int quality)
{
    int width = 0;
    int height = 0;
    s_frame_size_to_dim(size, &width, &height);
    if (width <= 0 || height <= 0) {
        return ESP_ERR_INVALID_SIZE;
    }

    const size_t rgb_bytes = (size_t)width * (size_t)height * 2;
    uint8_t *rgb = heap_caps_malloc(rgb_bytes, MALLOC_CAP_SPIRAM | MALLOC_CAP_8BIT);
    if (!rgb) {
        rgb = malloc(rgb_bytes);
    }
    if (!rgb) {
        return ESP_ERR_NO_MEM;
    }
    memset(rgb, 0, rgb_bytes);

    uint8_t *jpeg = NULL;
    size_t jpeg_len = 0;
    bool ok = fmt2jpg(rgb, rgb_bytes, width, height, PIXFORMAT_RGB565, quality, &jpeg, &jpeg_len);
    free(rgb);
    if (!ok || !jpeg || jpeg_len == 0) {
        if (jpeg) {
            free(jpeg);
        }
        return ESP_FAIL;
    }

    if (s_black_jpeg) {
        free(s_black_jpeg);
    }
    s_black_jpeg = jpeg;
    s_black_jpeg_len = jpeg_len;
    return ESP_OK;
}

// Records MJPEG frames to a file while the main recorder is active.
static void s_camera_record_task(void *arg)
{
    camera_task_args_t *args = (camera_task_args_t *)arg;
    FILE *f = fopen(args->path, "wb");
    if (!f) {
        int err = errno;
        ESP_LOGE(TAG, "Failed to open video file %s (errno=%d: %s)", args->path, err, strerror(err));
        s_camera_task = NULL;
        free(args);
        vTaskDelete(NULL);
        return;
    }

    size_t bytes_since_flush = 0;
    uint32_t bad_jpeg_count = 0;
    uint32_t good_frame_count = 0;
    while (button_is_recording()) {
        camera_fb_t *fb = esp_camera_fb_get();
        if (!fb) {
            ESP_LOGE(TAG, "Camera capture failed");
            vTaskDelay(pdMS_TO_TICKS(10));
            continue;
        }

        if (button_is_paused() && s_black_jpeg && s_black_jpeg_len > 0) {
            fwrite(s_black_jpeg, 1, s_black_jpeg_len, f);
            bytes_since_flush += s_black_jpeg_len;
        } else {
            if (fb->len < 4 || fb->buf[0] != 0xFF || fb->buf[1] != 0xD8 ||
                fb->buf[fb->len - 2] != 0xFF || fb->buf[fb->len - 1] != 0xD9) {
                bad_jpeg_count++;
                if ((bad_jpeg_count % 50) == 1) {
                    ESP_LOGW(TAG, "Skipping bad JPEG frame (SOI/EOI), count=%u", (unsigned)bad_jpeg_count);
                }
                esp_camera_fb_return(fb);
                vTaskDelay(pdMS_TO_TICKS(10));
                continue;
            }
            fwrite(fb->buf, 1, fb->len, f);
            bytes_since_flush += fb->len;
            good_frame_count++;
            if ((good_frame_count % 50) == 0) {
                ESP_LOGI(TAG, "Wrote %u frames (%u bad)", (unsigned)good_frame_count, (unsigned)bad_jpeg_count);
            }
        }

        esp_camera_fb_return(fb);

        if (bytes_since_flush >= VIDEO_FLUSH_BYTES) {
            fflush(f);
            fsync(fileno(f));
            bytes_since_flush = 0;
        }
    }

    fflush(f);
    fsync(fileno(f));
    fclose(f);
    s_camera_task = NULL;
    free(args);
    vTaskDelete(NULL);
}

void camera_app_log_i2c_levels(void)
{
    camera_ov2640_pins_t pins;
    camera_ov2640_get_default_pins(&pins);

    gpio_reset_pin(pins.pin_sda);
    gpio_reset_pin(pins.pin_scl);
    gpio_set_direction(pins.pin_sda, GPIO_MODE_INPUT);
    gpio_set_direction(pins.pin_scl, GPIO_MODE_INPUT);

    int sda = gpio_get_level(pins.pin_sda);
    int scl = gpio_get_level(pins.pin_scl);
    ESP_LOGI(TAG, "I2C idle levels: SDA=%d SCL=%d (expect 1)", sda, scl);
}
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

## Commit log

2026-01-18 Basic Recording controlled by single button press. Start and stop recording, pause and unpause recording
2026-01-24 added buzzer, OLED display for logging, fixed i2s sound quality issue by changing gpio pins, and added multiple back to back recordings
    [button.c, oled_ssd1306.c, sd_card_example_main.c]
2026-01-31 added schematics
    [Prototype.kicad_pcb, Prototype.kicad_sch]
2026-01-31 changed camera pins
2026-02-02 split camera/OLED I2C, stabilize OV2640 MJPEG capture, and harden SD/video file handling
    [button.c, camera_ov2640.c, oled_ssd1306.c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]
2026-02-02 Moved camera-related code into camera_ov2640.c, updated mic capture to its oown task, and added SD card mounting OLED error
2026-02-02 Updated README.md to include camera and cleaned it up
2026-02-10 reviewed schematic
    [Prototype.kicad_sch]
2026-02-10 added bluetooth control at the uuids 000...1 and 000...2 for short and long press
    [button.c, sd_card_example_main.c]
2026-02-10 Designed contact mic board schematic
    [Prototype.kicad_pcb, Prototype.kicad_sch]
2026-02-13 created keyfob board, cleaned up hardware folder
    [Keyfob Board.kicad_pcb, Keyfob Board.kicad_sch, Prototype.kicad_sch]
2026-02-14 revised contact mic board
    [Contact Mic Board.kicad_pcb, Contact Mic Board.kicad_sch, Main Board.kicad_pcb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]
2026-02-14 feat(cam/oled/ble/sd): stabilize OLED I2C, add BLE timestamps, set VGA
    Use I2C mutex for OLED writes and remove SD warning OLED updates
    Add BLE scan trigger and timestamped filenames for mic/video
    Fix frame size mapping and set default frame size to VGA
    [camera_ov2640.c, oled_ssd1306.c, sd_card_example_main.c]
2026-02-15 SD card schematic
    [Main Board.kicad_sch]
2026-02-15 Finally fit all components on the board!
2026-02-15 reviewed main board work done by Kevin
    [Main Board.kicad_sch]
2026-02-19 schematics for oled and mics
    [Adafruit OLED 128x32 Mono I2C STEMMA QT rev B.kicad_pcb, Adafruit OLED 128x32 Mono I2C STEMMA QT rev B.kicad_sch, Main Board.kicad_sch]
2026-02-20 drafted contact mic pcb layout
    [Contact Mic Board.kicad_pcb, Contact Mic Board.kicad_sch, Keyfob Board.kicad_pcb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]
2026-02-20 reviewed main board
    [Main Board.kicad_sch]
2026-02-21 Finalized layout for contact mic board
    [Contact Mic Board-B_Cu.gbr, Contact Mic Board-B_Mask.gbr, Contact Mic Board-B_Paste.gbr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]
2026-02-23 separated the microphone onto its own schematic as we won't be designing it. Updated the contact mic board
    [Adafruit Contact Mic I2S.kicad_pcb, Adafruit Contact Mic I2S.kicad_sch, Contact Mic Board.csv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]
2026-02-23 BLE triggering and time stamp bug fixes
    [sd_card_example_main.c]
2026-02-23 Added power management onto the main board schematic
    [Main Board.kicad_sch]
2026-02-24 drafted entire main board schematic and assigned footprints
    [Adafruit OLED 128x32 Mono I2C STEMMA QT rev B.kicad_sch, Main Board.kicad_pcb, Main Board.kicad_sch]
2026-02-26 drafted main board layout
    [Main Board.kicad_pcb, Main Board.kicad_sch]
2026-02-26 revised main board layout, rearranged around strapping pins, rererouted for noise
    [Main Board.kicad_pcb, Main Board.kicad_sch]
2026-03-02 reviewed most of main board, getting ready to finalize and prepare for manufacturing
    [Main Board.kicad_pcb, Main Board.kicad_sch]
2026-03-04 fixed sd card, checked manufacturing feasibility and cleaned up board layout
    [Main Board.kicad_pcb, Main Board.kicad_sch, bom.csv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]
